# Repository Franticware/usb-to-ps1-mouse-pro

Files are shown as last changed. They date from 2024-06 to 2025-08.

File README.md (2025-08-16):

# usb-to-ps1-mouse-pro

This is an adapter for connecting USB mouse to PS1. It emulates the original [SCPH-1090 PlayStation Mouse](https://en.wikipedia.org/wiki/PlayStation_Mouse).

It can also convert [keyboard key presses to controller button presses](https://franticware.github.io/usb-to-ps1-mouse-pro/keyboard.html).

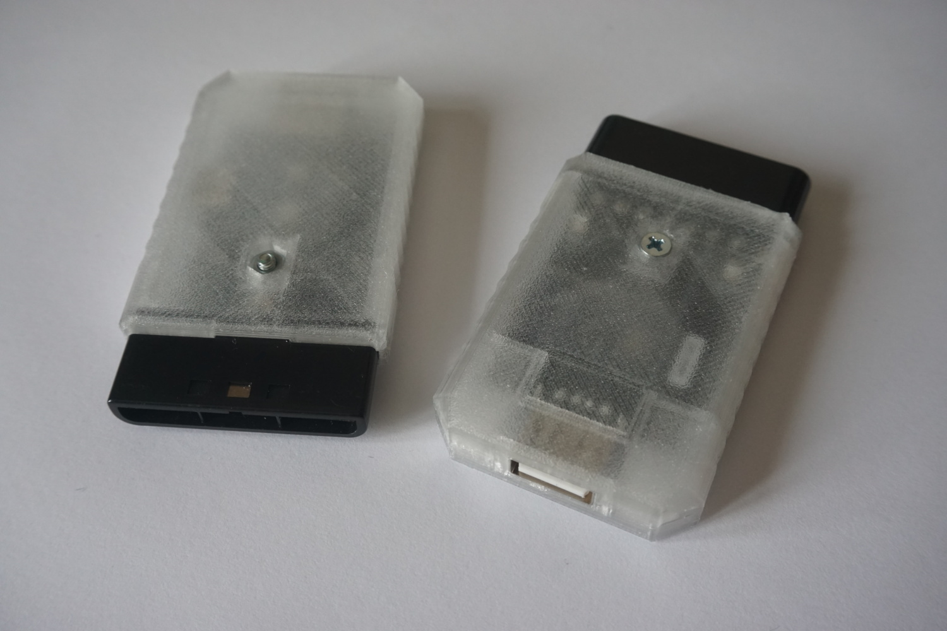
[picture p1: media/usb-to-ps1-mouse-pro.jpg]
PlayStation with USB mouse connected


## Availability

[Check here](https://www.franticware.com/usb-to-ps1-mouse-pro-availability) whether the adapter is available for purchase.

## Firmware

The firmware is written mostly in C. It depends on [Raspberry Pi Pico SDK](https://github.com/raspberrypi/pico-sdk).

For a guide on how to update the firmware, see [Flashing the Firmware](https://franticware.github.io/usb-to-ps1-mouse-pro/flashing.html).

## Hardware

See [kicad](kicad) subdirectory for schematics and PCB design files. Alternatively, check [wiring](wiring) subdirectory for laymen-friendly picture guide or if you are looking to rewire your older [usb-to-playstation-mouse](https://github.com/Franticware/usb-to-playstation-mouse) adapter.

## Enclosure

The enclosure is intended for the PCB-based variant. The handwired one will not fit.

Printing in clear PETG is recommended.

3D model: https://www.printables.com/model/914178-official-enclosure-for-usb-to-ps1-mouse-pro

## Notes

* Important:
  * Make sure the USB device is rated for 100 mA or less (most USB mice and keyboards are). Do not connect devices with higher (or unspecified) current draw.
* Known issues:
  * Fixed in PCB_3: Incompatible with PSOne (SCPH-10X), where there are issues such as game stuttering and console reset.
  * In rare cases, Lemmings might pause during gameplay.
  * USB mouse compatibility is not 100%. The same applies to USB keyboards.
* Gameplay video:

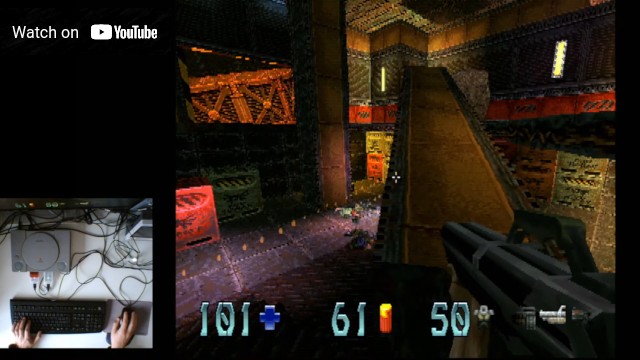
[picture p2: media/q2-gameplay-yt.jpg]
Quake II gameplay youtube video (https://youtu.be/i6l8ecVfj7o)


## References - GitHub

This project would not be possible without these. Please go give them a star.

https://github.com/sekigon-gonnoc/Pico-PIO-USB

https://github.com/listff/hidparser

## Support this project

To help this project, you can go listen to or even buy a [music track of mine](https://share.amuse.io/track/vojtech-salajka-color-graphics-pinball-original-game-soundtrack) via your favorite service. It is not much, but it is the only digital product I am currently offering commercially as of writing this. Thank you!

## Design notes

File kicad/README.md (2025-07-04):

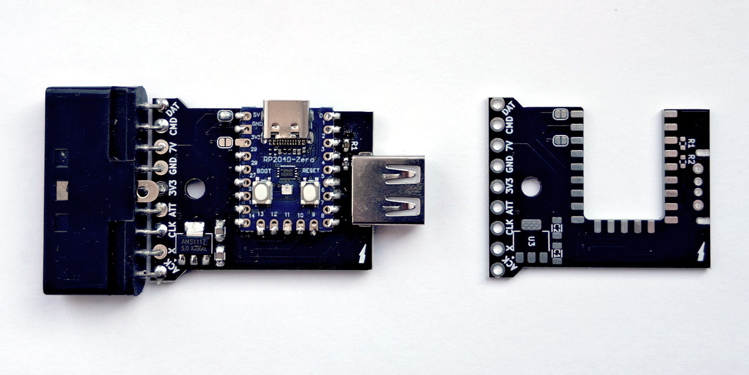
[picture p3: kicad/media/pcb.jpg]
PCB


## BOM

|Reference|Value|Datasheet|Footprint|Qty||
|-|-|-|-|-|-|
|C1, C2|10u/16V|~|Capacitor_SMD:C_1206_3216Metric|2||
|J1|Conn_01x09_Pin|~|PS1:Controller_THT90|1||
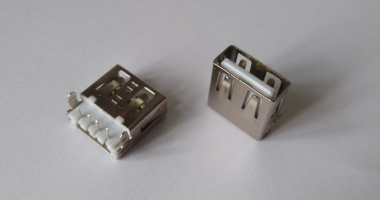
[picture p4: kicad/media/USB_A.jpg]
USB A
|J2|USB_A| ~|usb2ps1mouse-specific:USB_A_Sunken|1||
|J3|Conn_01x02|~|Jumper:SolderJumper-2_P1.3mm_Open_RoundedPad1.0x1.5mm|1|Short|
|J4|Conn_01x02|~|Jumper:SolderJumper-2_P1.3mm_Open_RoundedPad1.0x1.5mm|1|Do not short|
|R1, R2|22R|~|Resistor_SMD:R_0603_1608Metric|2||
|U1|RP2040-Zero||RP2040_Board:RP2040-Zero|1||
|U3|AMS1117-5.0|http://www.advanced-monolithic.com/pdf/ds1117.pdf|Package_TO_SOT_SMD:SOT-223-3_TabPin2|1||
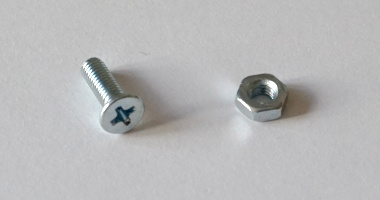
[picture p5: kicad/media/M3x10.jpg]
Bolt + nut
||M3x10 countersunk screw + M3 nut|||1+1||

## Manufacturing

I have had the boards made at https://jlcpcb.com using the following parameters:

- PCB Thickness: 1.6
- PCB Color: Black
- Silkscreen: White
- Material Type: FR4
- Via Covering: Tented
- Surface Finish: LeadFree HASL
- Outer Copper Weight: 1 oz
- Board Outline Tolerance: ±0.2mm (Regular)

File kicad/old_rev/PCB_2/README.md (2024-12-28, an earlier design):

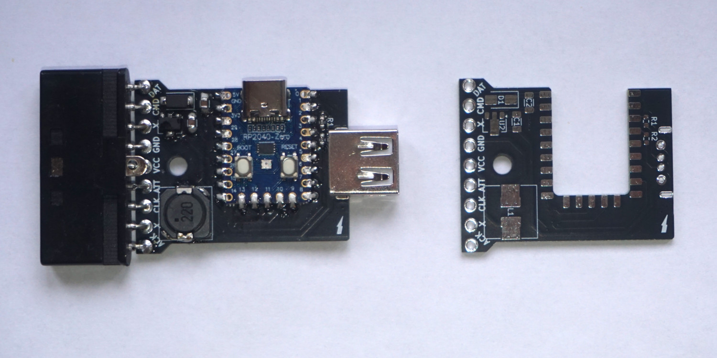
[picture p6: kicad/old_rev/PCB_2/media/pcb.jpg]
PCB


## BOM

|Reference|Value|Datasheet|Footprint|Qty||
|-|-|-|-|-|-|
|C1, C2|10u/16V|~|Capacitor_SMD:C_1206_3216Metric|2||
|D1|SS14|https://www.vishay.com/docs/88746/ss12.pdf|Diode_SMD:D_SMA|1||
|J1|Conn_01x09_Pin|~|PS1:Controller_THT90|1||
|J2|USB_A| ~|usb2ps1mouse-specific:USB_A_Sunken|1|USB A|
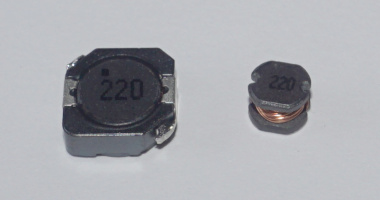
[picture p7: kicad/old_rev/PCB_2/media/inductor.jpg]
Inductor
|L1|22u|~|usb2ps1mouse-specific:L_combo|1||
|R1, R2|22R|~|Resistor_SMD:R_0603_1608Metric|2||
|U1|RP2040-Zero||RP2040_Board:RP2040-Zero|1||
|U2|ME2108A50PG||Package_TO_SOT_SMD:SOT-89-3|1||
||M3x10 countersunk screw + M3 nut|||1+1|Bolt + nut|

## Manufacturing

I have had the boards made at https://jlcpcb.com using the following parameters:

- PCB Thickness: 1.6
- PCB Color: Black
- Silkscreen: White
- Material Type: FR4
- Via Covering: Tented
- Surface Finish: LeadFree HASL
- Outer Copper Weight: 1 oz
- Board Outline Tolerance: ±0.2mm (Regular)

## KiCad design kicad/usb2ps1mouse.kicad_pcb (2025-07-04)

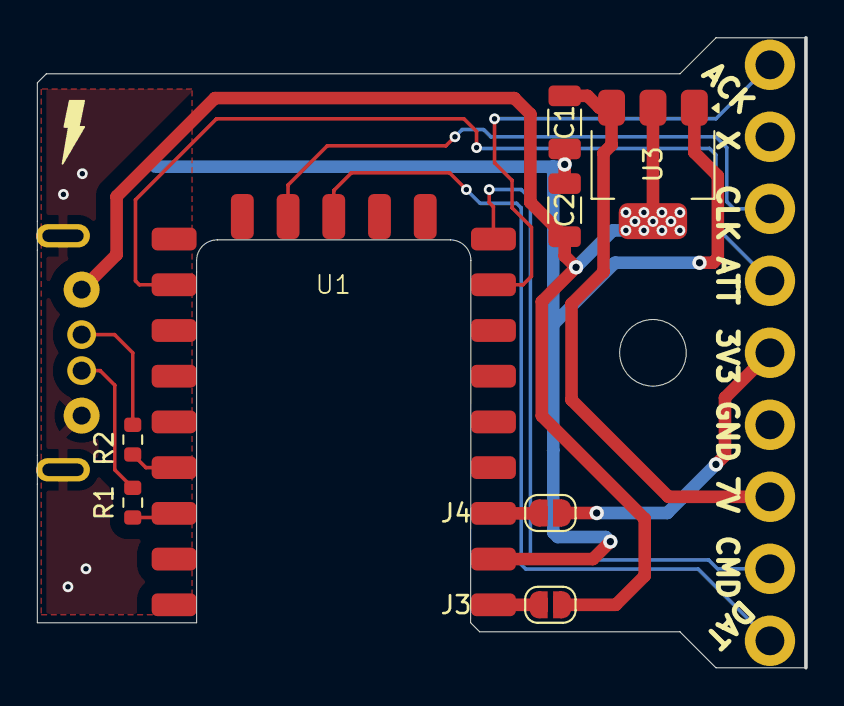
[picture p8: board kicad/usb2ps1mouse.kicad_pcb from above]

Board: 2 copper layers, 42.7 x 35.0 mm, 11 parts (1 on the bottom side), 15 nets.

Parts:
C1, C2: 10u/16V; C_1206_3216Metric
H1: MountingHole; MountingHole_3.7mm
J1: Conn_01x09_Pin; Controller_THT90
J2: USB_A; USB_A_Sunken
J3, J4: Conn_01x02; SolderJumper-2_P1.3mm_Open_RoundedPad1.0x1.5mm
R1, R2: 22R; R_0603_1608Metric
U1: RP2040-Zero
U3: AMS1117-5.0; SOT-223-3_TabPin2

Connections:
+5V: C2.1, J2.1 (VBUS), J3.1, U3.2 (VO)
ACK: J1.9, U1.16 (15)
ATT: J1.6, U1.8 (7)
CLK: J1.7, U1.11 (10)
CMD: J1.2, U1.15 (14)
DATA: J1.1, U1.12 (11)
DM: J2.2 (D-), R2.1
DP: J2.3 (D+), R1.1
GND: C1.2, C2.2, J1.4, J2.4 (GND), J2.5 (Shield), U1.22 (GND), U3.1 (GND)
unnamed: J3.2, U1.23 (5V)
unnamed: J4.2, U1.21 (3V3)
unnamed: R1.2, U1.3 (2)
unnamed: R2.2, U1.4 (3)
VCON: J1.5, J4.1
VMOT: C1.1, J1.3, U3.3 (VI)

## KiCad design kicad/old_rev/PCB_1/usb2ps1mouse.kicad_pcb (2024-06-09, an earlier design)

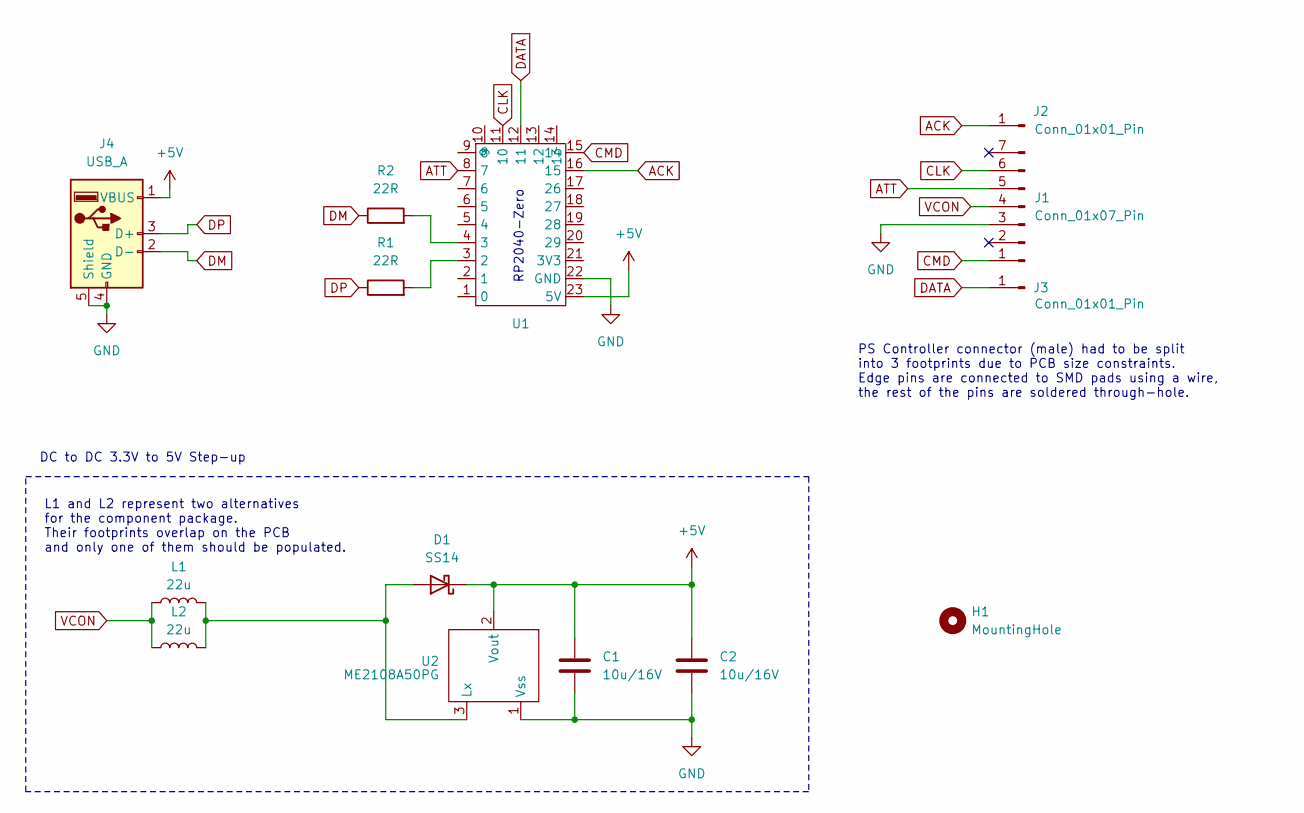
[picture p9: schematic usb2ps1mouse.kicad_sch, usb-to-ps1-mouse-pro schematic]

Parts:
C1, C2: 10u/16V; C_1206_3216Metric
D1: SS14; D_SMA
H1: MountingHole; MountingHole_3.7mm
J1: Conn_01x07_Pin; Controller_THT90
J2, J3: Conn_01x01_Pin; DSCON_pad
J4: USB_A; USB_A_Sunken
L1: 22u; L_10.4x10.4_H4.8
L2: 22u; L_Sumida_CR75
R1, R2: 22R; R_0603_1608Metric
U1: RP2040-Zero
U2: ME2108A50PG; SOT-89-3

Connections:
+5V: C1.1, C2.1, D1.1 (K), J4.1 (VBUS), U1.23 (5V), U2.2 (Vout)
ACK: J2.1, U1.16 (15)
ATT: J1.5, U1.8 (7)
CLK: J1.6, U1.11 (10)
CMD: J1.1, U1.15 (14)
DATA: J3.1, U1.12 (11)
DM: J4.2 (D-), R2.1
DP: J4.3 (D+), R1.1
GND: C1.2, C2.2, J1.3, J4.4 (GND), J4.5 (Shield), U1.22 (GND), U2.1 (Vss)
unnamed: D1.2 (A), L1.2, L2.2, U2.3 (Lx)
unnamed: R1.2, U1.3 (2)
unnamed: R2.2, U1.4 (3)
VCON: J1.4, L1.1, L2.1

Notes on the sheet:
PS Controller connector (male) had to be split into 3 footprints due to PCB size constraints. Edge pins are connected to SMD pads using a wire, the rest of the pins are soldered through-hole.
DC to DC 3.3V to 5V Step-up
RP2040-Zero
L1 and L2 represent two alternatives for the component package. Their footprints overlap on the PCB and only one of them should be populated.

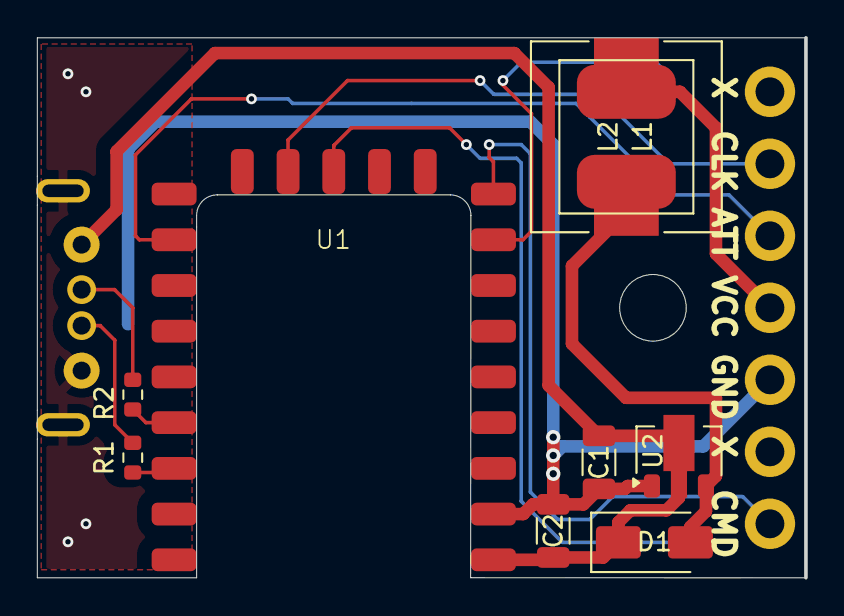
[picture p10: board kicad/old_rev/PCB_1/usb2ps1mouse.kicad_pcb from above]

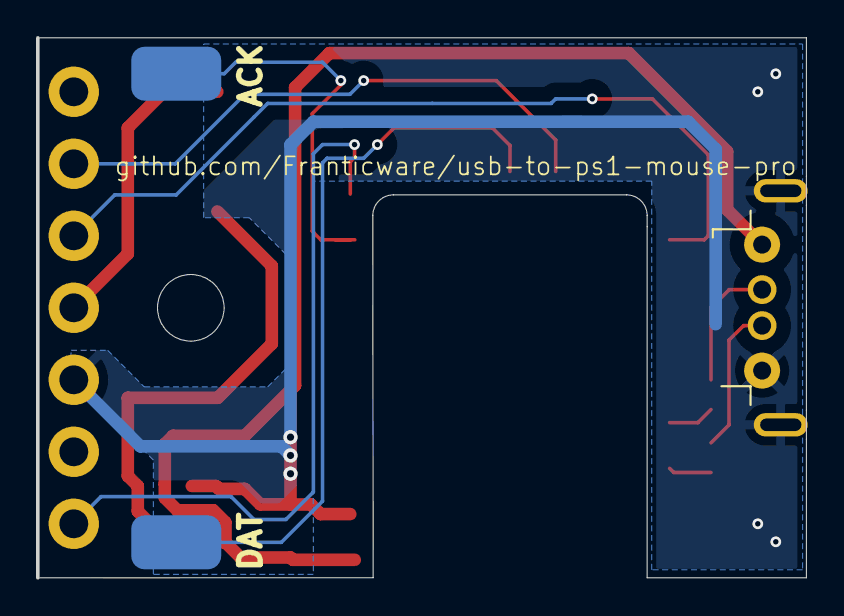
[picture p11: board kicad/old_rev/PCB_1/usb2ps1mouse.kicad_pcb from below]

Board: 2 copper layers, 42.7 x 30.0 mm, 14 parts (3 on the bottom side), 13 nets.

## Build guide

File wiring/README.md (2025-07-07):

## Handwiring the adapter

Building the PCB variant is recommended, but some may prefer this one. It does not look as good, but works just as well.

Components:

* PlayStation controller cable with connector
* Raspberry Pi Pico (or RP2040-Zero)
* USB A female connector
* AMS1117-5.0 voltage regulator module (5V output)
* 22 Ohm resistor (2 pcs)

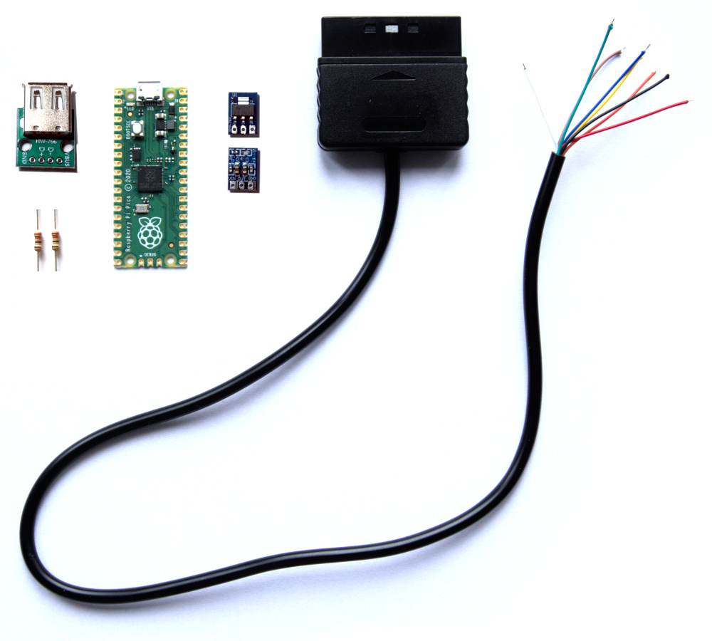
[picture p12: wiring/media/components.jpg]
Components


The cable has colored wires, but the color coding is not guaranteed and has to be checked with a multimeter in continuity mode. Unused wires have to be isolated.

The components are to be wired as follows:

Wiring diagram with Pi Pico

Or with RP2040-Zero:

Wiring diagram with RP2040-Zero

Make sure the components and wires do not short anywhere.

Flashing the firmware is done in the usual manner, i.e. the Pi is connected to a PC via a micro USB or USB-C cable while BOOTSEL or BOOT button is pressed. The Pi appears as USB flash drive and **uf2** file is copied to it.

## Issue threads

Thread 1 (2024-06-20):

More project info

LobAnovich, 2024-06-20:
Will description, BOM and diagrams be available?

Franticware, 2024-06-20:
Please see the `kicad` subdirectory

LobAnovich, 2024-06-20:
Are there plans to improve the circuit design of the board or is this the final version?

Franticware, 2024-06-20:
I have had the PCBs made and completed building a few pieces of this adapter. They are working pretty well, so that would be a yes. I cannot rule out slight changes in the future though, especially the PCB layout.

Franticware, 2024-06-21:
It is not.

Franticware, 2024-06-21:
It is not. The USB-C is now reserved to programming and debugging purposes.

Franticware, 2024-06-21:
It is not. The USB-C port is now reserved for programming and debugging purposes.

Franticware, 2024-06-22:
https://github.com/Franticware/usb-to-ps1-mouse-pro/tree/main/wiring

Franticware, 2025-07-04:
> Are there plans to improve the circuit design of the board or is this the final version?

There is now new revision PCB_3. Update to the wiring diagram will follow. It turns out previous versions of the board/wiring had issues with PSOne.

Closed 2024-06-22.

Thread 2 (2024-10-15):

Two end pins.

PSX-MAN, 2024-10-15:
Hello

Thank you for the awesome project and upgrade. I just have one question. These two pins are only connected to each other? Is it necessary to connect them?

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

Thank you

Franticware, 2024-10-15:
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
This is how it looks from the back. Also, the two pins tend to slide out as they are unsuported by the PCB. A drop of superglue might help. Not the best design, it will be resolved in the next PCB revision. There will also have to be a tweak to the 3D printed enclosure. I don't know when I get to fixing these issues, sorry.

Franticware, 2024-12-05:
@PSX-MAN The kicad directory now contains an updated PCB revision that should clarify things. Additional documentation will follow eventually.

PSX-MAN, 2024-12-05:
Great work, thank you very much.

Closed 2024-12-05.

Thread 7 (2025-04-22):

Restarts with PSIO clone with firmware 2.7 (build 19) Russian Version

diegomacielsc, 2025-04-22:
After updating PSIO clone from version 2.6 (build 28) to version 27 (build 19) when the adapter is inserted into the PSONE SCPH-100 and you try to turn on the console it restarts, with a non-modded console the problem does not occur.

diegomacielsc, 2025-04-23:
Thank you, and good work. 🙂

I purchased my PSone on AliExpress.

https://it.aliexpress.com/item/1005007469870363.html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

Attached photo.

Il giorno mar 22 apr 2025 alle ore 19:14 Vojtěch Salajka <
***@***.***> ha scritto:

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

--
Cordiali saluti,

Diego Maciel
379 1598130

diegomacielsc, 2025-04-24:
Thank you, and good work. 🙂

I purchased my PSone on AliExpress.

https://it.aliexpress.com/item/1005007469870363.html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

When I got my PSone, it had the old version of PSIO and it worked normally,
unfortunately after the update it stopped.

Attached photo.

Il giorno mar 22 apr 2025 alle ore 19:14 Vojtěch Salajka <
***@***.***> ha scritto:

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

--
Cordiali saluti,

Diego Maciel
379 1598130

Franticware, 2025-09-20:
Closing for now, please reopen if the issue crops up again.

Closed 2025-09-20.

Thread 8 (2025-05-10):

Keyboard version

hpx1984, 2025-05-10:
Hi Sir

i saw you use usb keyboard on 1P from your video ,so means this USB to PS1 mouse PRO also can support usb keyboard,right ?

jmi2k, 2025-05-10:
This really interests me but maybe not for the reason I think keyboards are currently supported.

Ideally, I'd like to use this device to simulate one of the few rare keyboard interfaces that were offered for the PS1 (the one corresponding to the Lightspan Online Connection CD, with ID 0x96 0x5A) as described [in this PSXDEV thread](https://www.psxdev.net/forum/viewtopic.php?f=54&t=140). I have a need for a simple USB to mouse/keyboard adapter device for a custom project, and while the protocol itself is not critical I think it would be neat to focus on the one that was official at some point and the community has already uncovered.

It would be a neat addition, even if optional (leaving the default KB-to-controller remapping functionality as the default).

Franticware, 2025-05-10:
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

I did not read the whole thread, but the device looks interesting. Anyone trying to implement support for it would need the original adapter to reverse-engineer it and some software that makes use of it to test the implementation. I do not have either.

jmi2k, 2025-05-12:
Unfortunately, getting one is practically impossible. _Somebody_ in the thread has one, there may be some out there in the wild, but that's about it.

OTOH, the protocol was reverse-engineered from the Online Connection CD (the byte sequence at least):

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

Now, this is not enough to get the full picture (no mention of clock rate nor potential quirks of the HW interface) but it's a good start.

hpx1984, 2025-05-13:
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

That's the good news , hope you can finish this keyboard project quickly , i can't wait to try it

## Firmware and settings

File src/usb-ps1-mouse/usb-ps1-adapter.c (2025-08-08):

#include <stdio.h>
#include <stdlib.h>
#include <string.h>

#include "hardware/clocks.h"
#include "hardware/pio.h"
#include "parsemouse.h"
#include "pico/bootrom.h"
#include "pico/multicore.h"
#include "pico/stdlib.h"
#include "ws2812.pio.h"

#define PIO_USB_DP_PIN_DEFAULT 2 // must be before usb headers

#include "pio_usb.h"
#include "tusb.h"

//--------------------------------------------------------------------+
// MACRO CONSTANT TYPEDEF PROTYPES
//--------------------------------------------------------------------+

#define DEBUG_STDOUT 0

#define IS_RGBW false
#define WS2812_PIN 16

#define GP_ATT 7
#define GP_CLK 10
#define GP_DAT 11
#define GP_CMD 14
#define GP_ACK 15

#define PIX_OFF 0
#define PIX_BLINK 1
#define PIX_MOUSE 2
#define PIX_KEYB 3
#define PIX_CLICK 4
#define PIX_OVF 5

#define COLOR_BLACK 0x000000
#define COLOR_FAINT_MOUSE_GREEN 0x020001
#define COLOR_FAINT_KEYBOARD_VIOLET 0x000202
#define COLOR_FAINT_RED 0x000300
#define COLOR_FAINT_WARM_WHITE 0x020201

static const uint16_t KEY_BUTTON_MAP[4 + 8 + 256 + 4] = {
    0x454b, 0x4d59, 0x5041, 0x3e3e, 0,      0,      0,      0,      0x0008,
    0x0001, 0,      0,      0,      0,      0,      0,      0x0080, 0,
    0,      0x0020, 0x0100, 0x4000, 0x2000, 0,      0x0200, 0,      0x8000,
    0x4000, 0,      0,      0x1000, 0x0800, 0x0400, 0x8000, 0x0040, 0x1000,
    0,      0,      0x0010, 0,      0,      0,      0,      0,      0,
    0,      0,      0,      0,      0,      0,      0,      0x0008, 0,
    0x0001, 0,      0,      0,      0,      0,      0,      0,      0,
    0x2000, 0,      0,      0,      0,      0,      0,      0,      0,
    0,      0,      0,      0,      0,      0,      0,      0,      0,
    0,      0,      0,      0,      0,      0,      0,      0,      0,
    0,      0x0020, 0x0080, 0x0040, 0x0010, 0,      0,      0,      0,
    0,      0,      0,      0,      0,      0,      0,      0,      0,
    0,      0,      0,      0,      0,      0,      0,      0,      0,
    0,      0,      0,      0,      0,      0,      0,      0,      0,
    0,      0,      0,      0,      0,      0,      0,      0,      0,
    0,      0,      0,      0,      0,      0,      0,      0,      0,
    0,      0,      0,      0,      0,      0,      0,      0,      0,
    0,      0,      0,      0,      0,      0,      0,      0,      0,
    0,      0,      0,      0,      0,      0,      0,      0,      0,
    0,      0,      0,      0,      0,      0,      0,      0,      0,
    0,      0,      0,      0,      0,      0,      0,      0,      0,
    0,      0,      0,      0,      0,      0,      0,      0,      0,
    0,      0,      0,      0,      0,      0,      0,      0,      0,
    0,      0,      0,      0,      0,      0,      0,      0,      0,
    0,      0,      0,      0,      0,      0,      0,      0,      0,
    0,      0,      0,      0,      0,      0,      0,      0,      0,
    0,      0,      0,      0,      0,      0,      0,      0,      0,
    0,      0,      0,      0,      0,      0,      0,      0,      0,
    0,      0,      0,      0,      0,      0,      0,      0,      0,
    0,      0,      0,      0,      0,      0,      0,      0x3c3c, 0x454b,
    0x4d59, 0x5041,
};

static const uint16_t *KEY_PTR = KEY_BUTTON_MAP + 4 + 8;
static const uint16_t *MOD_PTR = KEY_BUTTON_MAP + 4;

/*------------- MAIN -------------*/

auto_init_mutex(mtx);
uint8_t gPixState = PIX_BLINK;

// core1: handle host events
void core1_main() {
  sleep_ms(10);

  // Use tuh_configure() to pass pio configuration to the host stack
  tuh_hid_set_default_protocol(HID_PROTOCOL_REPORT);
  pio_usb_configuration_t pio_cfg = PIO_USB_DEFAULT_CONFIG;
  tuh_configure(1, TUH_CFGID_RPI_PIO_USB_CONFIGURATION, &pio_cfg);

  // To run USB SOF interrupt in core1, init host stack for pio_usb (roothub
  // port1) on core1
  tuh_init(1);

  PIO pio;
  uint sm;
  uint offset;

  // This will find a free pio and state machine for our program and load it for
  // us We use pio_claim_free_sm_and_add_program_for_gpio_range (for_gpio_range
  // variant) so we will get a PIO instance suitable for addressing gpios >= 32
  // if needed and supported by the hardware
  bool success = pio_claim_free_sm_and_add_program_for_gpio_range(
      &ws2812_program, &pio, &sm, &offset, WS2812_PIN, 1, true);
  hard_assert(success);

  ws2812_program_init(pio, sm, offset, WS2812_PIN, 800000, IS_RGBW);

  uint64_t prevTime = to_us_since_boot(get_absolute_time());

  uint64_t timeSum = 0;

  const uint64_t updatePeriod = 50 * 1000; // 50k us = 20 upd/s

  uint8_t blinkI = 0;

  uint32_t pixGRB = 0;

  while (true) {
    tuh_task(); // tinyusb host task

    uint64_t currTime = to_us_since_boot(get_absolute_time());
    timeSum += (currTime - prevTime);
    prevTime = currTime;

    if (timeSum >= updatePeriod) {
      timeSum -= updatePeriod;
      mutex_enter_blocking(&mtx);
      const uint8_t pixStateTmp = gPixState;
      mutex_exit(&mtx);
      switch (pixStateTmp) {
      case PIX_OFF:
        pixGRB = COLOR_BLACK;
        break;
      case PIX_BLINK:
        if (blinkI < 10) {
          pixGRB = COLOR_FAINT_WARM_WHITE;
        } else {
          pixGRB = COLOR_BLACK;
        }
        break;
      case PIX_MOUSE:
        pixGRB = COLOR_FAINT_MOUSE_GREEN;
        break;
      case PIX_KEYB:
        pixGRB = COLOR_FAINT_KEYBOARD_VIOLET;
        break;
      case PIX_OVF:
        pixGRB = COLOR_FAINT_RED;
        break;
      case PIX_CLICK:
        pixGRB = COLOR_FAINT_WARM_WHITE;
        break;
      default:
        mutex_enter_blocking(&mtx);
        gPixState = PIX_OFF;
        mutex_exit(&mtx);
        pixGRB = COLOR_BLACK;
        break;
      }
      ++blinkI;
      if (blinkI == 20) {
        blinkI = 0;
      }
      pio_sm_put_blocking(pio, sm, pixGRB << 8u);
    }
  }
}

enum EState : uint8_t { SM_A0 = 0, SM_A1 = 1, SM_A0C1 = 2, SM_A0C0 = 3 };

typedef struct {
  enum EState state;
  uint8_t bitIndex;
  uint8_t byteIndex;
  uint8_t cmd[2];
  uint8_t data[10]; // mouse/pad data
  uint8_t size;     // mouse/pad data size
} ConSM;

static ConSM gSM;

enum EProt : uint8_t { PROT_NONE = 0, PROT_KEYB = 1, PROT_MOUSE = 2 };

static enum EProt gContrProt = PROT_NONE;

static int8_t gSumX = 0;
static int8_t gSumY = 0;
static bool gL = false;
static bool gR = false;

static uint16_t gButtons = 0;

// sum with saturation
int8_t sumSat(int8_t a, int8_t b) {
  int16_t ret = (int16_t)a + (int16_t)b;
  if (ret < -128)
    ret = -128;
  if (ret > 127)
    ret = 127;
  return ret;
}

void SM_init() {
  if (gpio_get(GP_ATT)) {
    gSM.state = SM_A1;
  } else {
    gSM.state = SM_A0;
  }
}

void SM_task() {
  switch (gSM.state) {
  case SM_A0: {
    gpio_set_dir(GP_DAT, GPIO_IN);
    if (gpio_get(GP_ATT)) {
      gSM.state = SM_A1;
    }
    break;
  }
  case SM_A1: {
    gpio_set_dir(GP_DAT, GPIO_IN);
    if (!gpio_get(GP_ATT)) {
      gSM.bitIndex = gSM.byteIndex = 0;
      gSM.cmd[0] = gSM.cmd[1] = 0;
      gSM.state = SM_A0C1;
    }
    break;
  }
  case SM_A0C1: {
    if (!gpio_get(GP_CLK)) {
      gSM.state = SM_A0C0;
      // falling edge clock
      if (gSM.byteIndex > 0 && gSM.byteIndex <= gSM.size) {
        if (gSM.data[gSM.byteIndex - 1] & (1 << gSM.bitIndex)) {
          gpio_set_dir(GP_DAT, GPIO_IN);
        } else {
          gpio_set_dir(GP_DAT, GPIO_OUT);
        }
      }
    } else if (gpio_get(GP_ATT)) {
      gSM.state = SM_A1;
    }
    break;
  }
  case SM_A0C0: {
    if (gpio_get(GP_CLK)) {
      gSM.state = SM_A0C1;
      // rising edge clock
      if (gpio_get(GP_CMD)) {
        if (gSM.byteIndex < 2) {
          gSM.cmd[gSM.byteIndex] |= 1 << (gSM.bitIndex);
        }
      }
      ++gSM.bitIndex;
      if (gSM.bitIndex == 8) {
        gSM.bitIndex = 0;
        // sleep_us(11);
        sleep_us(15);
        gpio_set_dir(GP_DAT, GPIO_IN);
        if (gSM.byteIndex < gSM.size) {
          gpio_set_dir(GP_ACK, GPIO_OUT);
          // sleep_us(3);
          sleep_us(4);
          gpio_set_dir(GP_ACK, GPIO_IN);
        }

        if (gSM.byteIndex == 0) {
          if (gSM.cmd[gSM.byteIndex] != 1) {
            gSM.state = SM_A0;
            break;
          } else {
            mutex_enter_blocking(&mtx);
            if (gContrProt == PROT_MOUSE) {
              uint8_t buttons1 = 3;
              int8_t sumX = gSumX;
              gSumX = 0;
              int8_t sumY = gSumY;
              gSumY = 0;
              if (gL) {
                buttons1 |= 8;
              }
              if (gR) {
                buttons1 |= 4;
              }
              mutex_exit(&mtx);
              gSM.size = 6;
              gSM.data[0] = 0x12;
              gSM.data[1] = 0x5A;
              gSM.data[2] = 0xFF;
              gSM.data[3] = ~buttons1;
              gSM.data[4] = sumX;
              gSM.data[5] = sumY;
            } else if (gContrProt == PROT_KEYB) {
              uint16_t buttons = gButtons;
              mutex_exit(&mtx);
              gSM.size = 4;
              gSM.data[0] = 0x41;
              gSM.data[1] = 0x5A;
              gSM.data[2] = ~buttons;
              gSM.data[3] = ~(buttons >> 8);
            } else {
              mutex_exit(&mtx);
              gSM.size = 4;
              gSM.data[0] = 0x41;
              gSM.data[1] = 0x5A;
              gSM.data[2] = 0xFF;
              gSM.data[3] = 0xFF;
            }
          }
        } else if (gSM.byteIndex == 1) {
          if (gSM.cmd[gSM.byteIndex] != 0x42) {
            gSM.state = SM_A0;
            break;
          }
        }
        ++gSM.byteIndex;
      }
    } else if (gpio_get(GP_ATT)) {
      gSM.state = SM_A1;
    }
    break;
  }
  }
}

// core0: handle device events
int main(void) {
  // default 125MHz is not appropriate. Sysclock should be multiple of 12MHz.
  set_sys_clock_khz(120000, true);

  sleep_ms(10);

#if DEBUG_STDOUT
  stdio_init_all();
#endif

  multicore_reset_core1();
  // all USB task run in core1
  multicore_launch_core1(core1_main);

  gpio_init(GP_ATT);
  gpio_set_dir(GP_ATT, GPIO_IN);

  gpio_init(GP_CLK);
  gpio_set_dir(GP_CLK, GPIO_IN);

  gpio_init(GP_DAT);
  gpio_set_slew_rate(GP_DAT, GPIO_SLEW_RATE_SLOW);
  gpio_set_dir(GP_DAT, GPIO_IN);
  gpio_clr_mask((1 << GP_DAT));

  gpio_init(GP_CMD);
  gpio_set_dir(GP_CMD, GPIO_IN);

  gpio_init(GP_ACK);
  gpio_set_slew_rate(GP_ACK, GPIO_SLEW_RATE_SLOW);
  gpio_set_dir(GP_ACK, GPIO_IN);
  gpio_clr_mask((1 << GP_ACK));

  SM_init();

  while (true) {
    SM_task();
  }

  return 0;
}

//--------------------------------------------------------------------+
// Host HID
//--------------------------------------------------------------------+

bool testKeyboardDescr(const volatile uint8_t *descr, uint32_t descrLen) {
  return descrLen > 4 && descr[0] == 0x05 && descr[1] == 0x01 &&
         descr[2] == 0x09 && descr[3] == 0x06;
}

bool parseKeyboardData(const uint8_t *data, uint32_t dataLen,
                       uint16_t *buttonsPtr) {
  if (dataLen != 8) {
    return false;
  }
  if (data[2] == 1 || data[3] == 1 || data[4] == 1 || data[5] == 1 ||
      data[6] == 1 || data[7] == 1) {
    return false;
  }
  uint16_t buttons = 0;
  for (int i = 0; i != 8; ++i) {
    if (data[0] & (1 << i)) {
      buttons |= MOD_PTR[i];
    }
  }
  for (int i = 2; i != 8; ++i) {
    if (data[i]) {
      buttons |= KEY_PTR[data[i]];
    }
  }
  *buttonsPtr = buttons;
  return true;
}

typedef struct {
  uint8_t protocol;
  uint8_t dev_addr;
  uint8_t instance;
  MouseConf mouse;
} USBDev;

#define gUSBDevsCount 8
static USBDev gUSBDevs[gUSBDevsCount] = {{0}, {0}, {0}, {0},
                                         {0}, {0}, {0}, {0}};

USBDev *findEmptyDev() {
  for (uint8_t i = 0; i != gUSBDevsCount; ++i) {
    if (gUSBDevs[i].protocol == PROT_NONE) {
      return gUSBDevs + i;
    }
  }
  return NULL;
}

USBDev *findDev(uint8_t dev_addr, uint8_t instance) {
  for (uint8_t i = 0; i != gUSBDevsCount; ++i) {
    if (gUSBDevs[i].dev_addr == dev_addr && gUSBDevs[i].instance == instance) {
      return gUSBDevs + i;
    }
  }
  return NULL;
}

// Invoked when device with hid interface is mounted
// Report descriptor is also available for use.
// tuh_hid_parse_report_descriptor() can be used to parse common/simple enough
// descriptor. Note: if report descriptor length > CFG_TUH_ENUMERATION_BUFSIZE,
// it will be skipped therefore report_desc = NULL, desc_len = 0
void tuh_hid_mount_cb(uint8_t dev_addr, uint8_t instance,
                      uint8_t const *desc_report, uint16_t desc_len) {

  // Interface protocol (hid_interface_protocol_enum_t)
  uint8_t const itf_protocol = tuh_hid_interface_protocol(dev_addr, instance);

  uint16_t vid, pid;
  tuh_vid_pid_get(dev_addr, &vid, &pid);

#if DEBUG_STDOUT
  const char *protocol_str[] = {"None", "Keyboard", "Mouse"};

  uint64_t currentTime = to_us_since_boot(get_absolute_time());

  printf("{\"event\":\"mount\",\"timestamp\":\"%llu\",\"vid\":\"%04x\",\"pid\":"
         "\"%04x\",\"address\":\"%u\",\"instance\":\"%u\",\"protocol\":\"%s\",",
         currentTime, vid, pid, dev_addr, instance, protocol_str[itf_protocol]);

  printf("\"data\":\"");

  for (int i = 0; i != desc_len; ++i) {
    if (i != 0)
      printf(" ");
    printf("%02x", desc_report[i]);
  }
  printf("\"");
#endif

  if (itf_protocol == PROT_KEYB) {
    USBDev *usbdev = NULL;
    if (testKeyboardDescr(desc_report, desc_len)) {
      if ((usbdev = findEmptyDev())) {
        usbdev->protocol = PROT_KEYB;
        usbdev->dev_addr = dev_addr;
        usbdev->instance = instance;
        mutex_enter_blocking(&mtx);
        gPixState = PIX_KEYB;
        gContrProt = PROT_KEYB;
        mutex_exit(&mtx);
      }
    }
  } else if (itf_protocol == PROT_MOUSE) {
    USBDev *usbdev = NULL;
    MouseConf mouseConfTmp;
    parseMouseDescr(desc_report, desc_len, &mouseConfTmp);
    if (mouseConfTmp.xI != 255 && mouseConfTmp.yI != 255) {
      if ((usbdev = findEmptyDev())) {
        usbdev->protocol = PROT_MOUSE;
        usbdev->dev_addr = dev_addr;
        usbdev->instance = instance;
        usbdev->mouse = mouseConfTmp;
        mutex_enter_blocking(&mtx);
        gPixState = PIX_MOUSE;
        gContrProt = PROT_MOUSE;
        mutex_exit(&mtx);
      }
    }
  }

  // Receive report from boot keyboard & mouse only
  // tuh_hid_report_received_cb() will be invoked when report is available
  if (itf_protocol == HID_ITF_PROTOCOL_KEYBOARD ||
      itf_protocol == HID_ITF_PROTOCOL_MOUSE) {
    if (!tuh_hid_receive_report(dev_addr, instance)) {
#if DEBUG_STDOUT
      printf(",\"error\":\"cannot request report\"");
#endif
    }
  }
#if DEBUG_STDOUT
  printf("},\n");
#endif
}

// Invoked when device with hid interface is un-mounted
void tuh_hid_umount_cb(uint8_t dev_addr, uint8_t instance) {
#if DEBUG_STDOUT
  uint64_t currentTime = to_us_since_boot(get_absolute_time());
  printf("{\"event\":\"umount\",\"timestamp\":\"%llu\",\"address\":\"%u\","
         "\"instance\":\"%u\"},\n",
         currentTime, dev_addr, instance);
#endif

  USBDev *usbdev = NULL;
  if ((usbdev = findDev(dev_addr, instance))) {
    usbdev->protocol = PROT_NONE;
  }
}

// Invoked when received report from device via interrupt endpoint
void tuh_hid_report_received_cb(uint8_t dev_addr, uint8_t instance,
                                uint8_t const *report, uint16_t len) {

#if DEBUG_STDOUT
  uint64_t currentTime = to_us_since_boot(get_absolute_time());

  printf("{\"event\":\"report\",\"timestamp\":\"%llu\",\"address\":\"%u\","
         "\"instance\":\"%u\",",
         currentTime, dev_addr, instance);

  printf("\"data\":\"");

  for (int i = 0; i != len; ++i) {
    if (i != 0)
      printf(" ");
    printf("%02x", report[i]);
  }
  printf("\"");
#endif

  // continue to request to receive report
  if (!tuh_hid_receive_report(dev_addr, instance)) {
#if DEBUG_STDOUT
    printf(",\"error\":\"cannot request report\"");
#endif
  }

#if DEBUG_STDOUT
  printf("},\n");
#endif

  USBDev *usbdev = NULL;
  if ((usbdev = findDev(dev_addr, instance))) {
    if (usbdev->protocol == PROT_MOUSE) {
      int8_t o[4];
      if (parseMouseData(report, len, &usbdev->mouse, o) == 0) {
        mutex_enter_blocking(&mtx);
        gSumX = sumSat(gSumX, o[1]);
        gSumY = sumSat(gSumY, o[2]);
        gL = o[0] & 1;
        gR = o[0] & 2;
        gContrProt = PROT_MOUSE;
        gPixState = gL ? PIX_CLICK : PIX_MOUSE;
        mutex_exit(&mtx);
      }
    } else if (usbdev->protocol == PROT_KEYB) {
      uint16_t buttons = 0;
      if (parseKeyboardData(report, len, &buttons)) {
        mutex_enter_blocking(&mtx);
        gSumX = 0;
        gSumY = 0;
        gButtons = buttons;
        gContrProt = PROT_KEYB;
        gPixState = buttons & 8 ? PIX_CLICK : PIX_KEYB;
        mutex_exit(&mtx);
      } else {
        mutex_enter_blocking(&mtx);
        gSumX = 0;
        gSumY = 0;
        gContrProt = PROT_KEYB;
        gPixState = PIX_OVF;
        mutex_exit(&mtx);
      }
    }
  }
}

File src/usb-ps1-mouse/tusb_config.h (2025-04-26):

/*
 * The MIT License (MIT)
 *
 * Copyright (c) 2019 Ha Thach (tinyusb.org)
 *
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
 */

#ifndef _TUSB_CONFIG_H_
#define _TUSB_CONFIG_H_

#ifdef __cplusplus
extern "C" {
#endif

//--------------------------------------------------------------------
// COMMON CONFIGURATION
//--------------------------------------------------------------------

#define CFG_TUSB_OS OPT_OS_PICO

// Do not enable device stack
#define CFG_TUD_ENABLED 0

// Enable host stack with pio-usb if Pico-PIO-USB library is available
#define CFG_TUH_ENABLED 1
#define CFG_TUH_RPI_PIO_USB 1

// CFG_TUSB_DEBUG is defined by compiler in DEBUG build
// #define CFG_TUSB_DEBUG           0

/* USB DMA on some MCUs can only access a specific SRAM region with restriction
 * on alignment. Tinyusb use follows macros to declare transferring memory so
 * that they can be put into those specific section. e.g
 * - CFG_TUSB_MEM SECTION : __attribute__ (( section(".usb_ram") ))
 * - CFG_TUSB_MEM_ALIGN   : __attribute__ ((aligned(4)))
 */
#ifndef CFG_TUSB_MEM_SECTION
#define CFG_TUSB_MEM_SECTION
#endif

#ifndef CFG_TUSB_MEM_ALIGN
#define CFG_TUSB_MEM_ALIGN __attribute__((aligned(4)))
#endif

//--------------------------------------------------------------------
// HOST CONFIGURATION
//--------------------------------------------------------------------

// Size of buffer to hold descriptors and other data used for enumeration
#define CFG_TUH_ENUMERATION_BUFSIZE 256

#define CFG_TUH_HUB 1
// max device support (excluding hub device)
#define CFG_TUH_DEVICE_MAX (CFG_TUH_HUB ? 4 : 1) // hub typically has 4 ports

#define CFG_TUH_HID 4
#define CFG_TUH_HID_EPIN_BUFSIZE 64
#define CFG_TUH_HID_EPOUT_BUFSIZE 64

#ifdef __cplusplus
}
#endif

#endif /* _TUSB_CONFIG_H_ */

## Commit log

2024-06-02 Register all button state changes, keep data until fully transmitted.
2024-06-09 Add KiCad project
    [usb2ps1mouse.kicad_pcb, usb2ps1mouse.kicad_sch]
2024-06-20 Update schematic
    Add BOM
    [usb2ps1mouse.kicad_sch]
2024-06-22 Add wiring diagram for RP2040-Zero
2024-09-01 Add RGB LED indication.
2024-09-07 Reduce RGB LED's initial green flash.
    Add forgotten RGB LED driver.
2024-09-10 Change RGB LED color scheme.
    Fix stray stdio_flush
2024-09-10 Light up RGB LED from the start
2024-12-05 Move old PCB revision
    [usb2ps1mouse.kicad_pcb, usb2ps1mouse.kicad_sch]
2024-12-05 Add PCB_2 revision
    [usb2ps1mouse.kicad_pcb, usb2ps1mouse.kicad_sch]
2024-12-28 Add Readme for kicad files
2025-04-25 Get rid of CDC USB device.
2025-04-26 Add ws2812 library from pico-examples
2025-04-27 Fix output byte format, update autoflash
    [usb-ps1-adapter.c]
2025-07-02 Update RGB LED handling.
2025-07-04 Add pico-sdk hotfix.
2025-07-04 Add PCB_3 board revision.
    [usb2ps1mouse.kicad_pcb, usb2ps1mouse.kicad_sch]
2025-07-04 Update BOM.
2025-07-05 Add PCB photo.
2025-07-07 Update wiring to match PCB_3.
2025-08-16 Fix readme, revert debug code
    [usb-ps1-adapter.c]
